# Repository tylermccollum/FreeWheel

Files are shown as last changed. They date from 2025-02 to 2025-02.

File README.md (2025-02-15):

BLDC motors represent an opportunity for massive improvements in hobby 
robotics work, but is largely limited by the cost. You can get a 
serviceable motor for less than $5, but the driver to use it starts at 
$40. The goal for this project is to create an open-source 100W BLDC 
servo controller design with a BOM cost under $10 and an accompanying 
library for control to standardize open-source FOC work.

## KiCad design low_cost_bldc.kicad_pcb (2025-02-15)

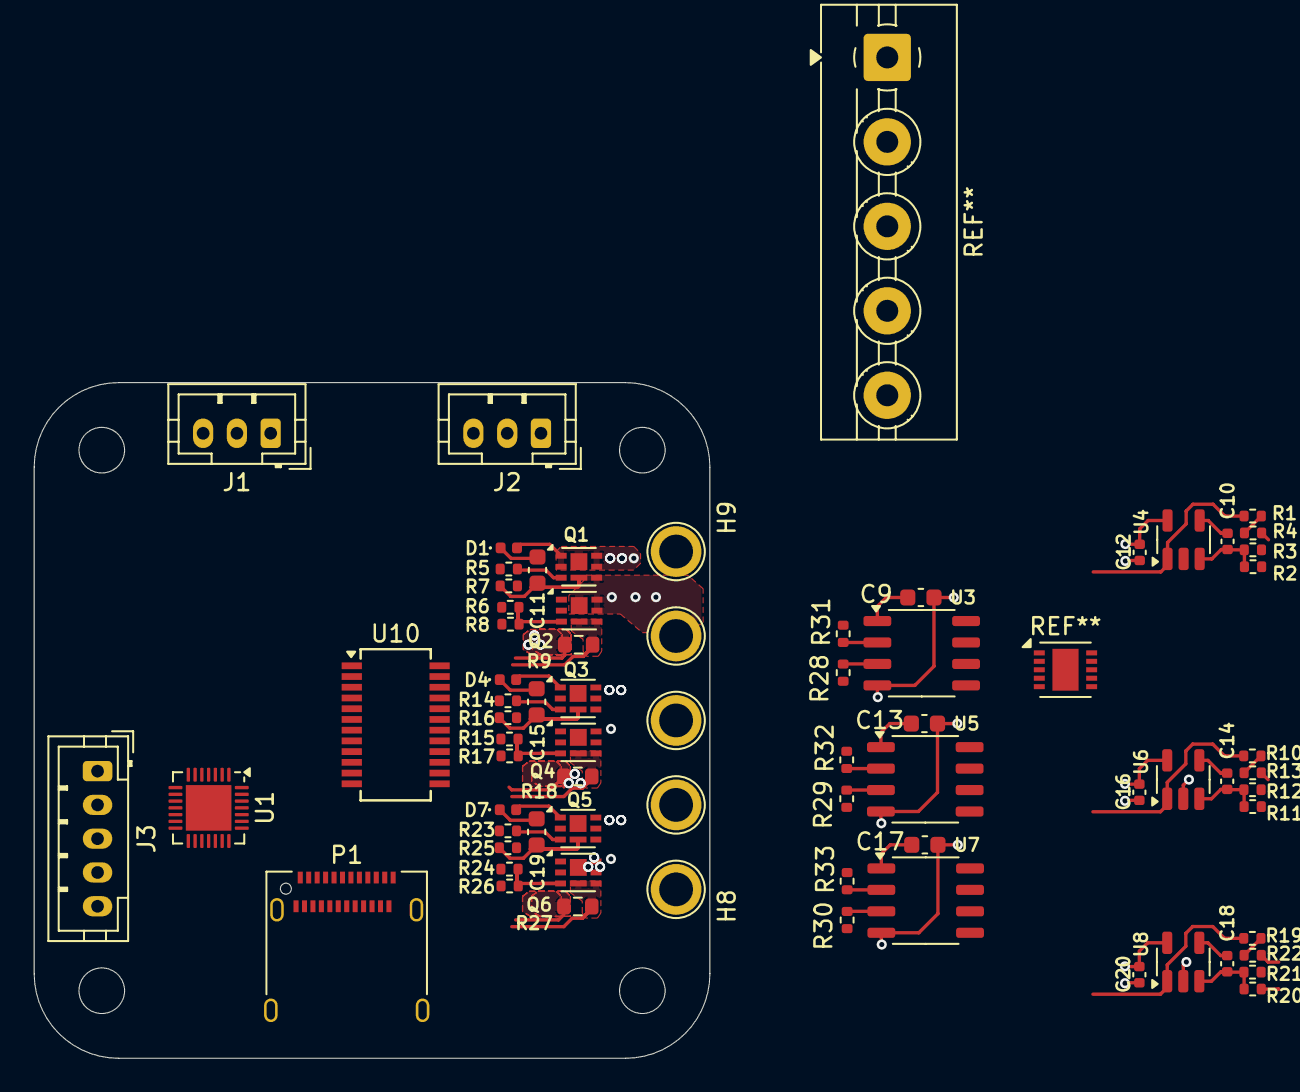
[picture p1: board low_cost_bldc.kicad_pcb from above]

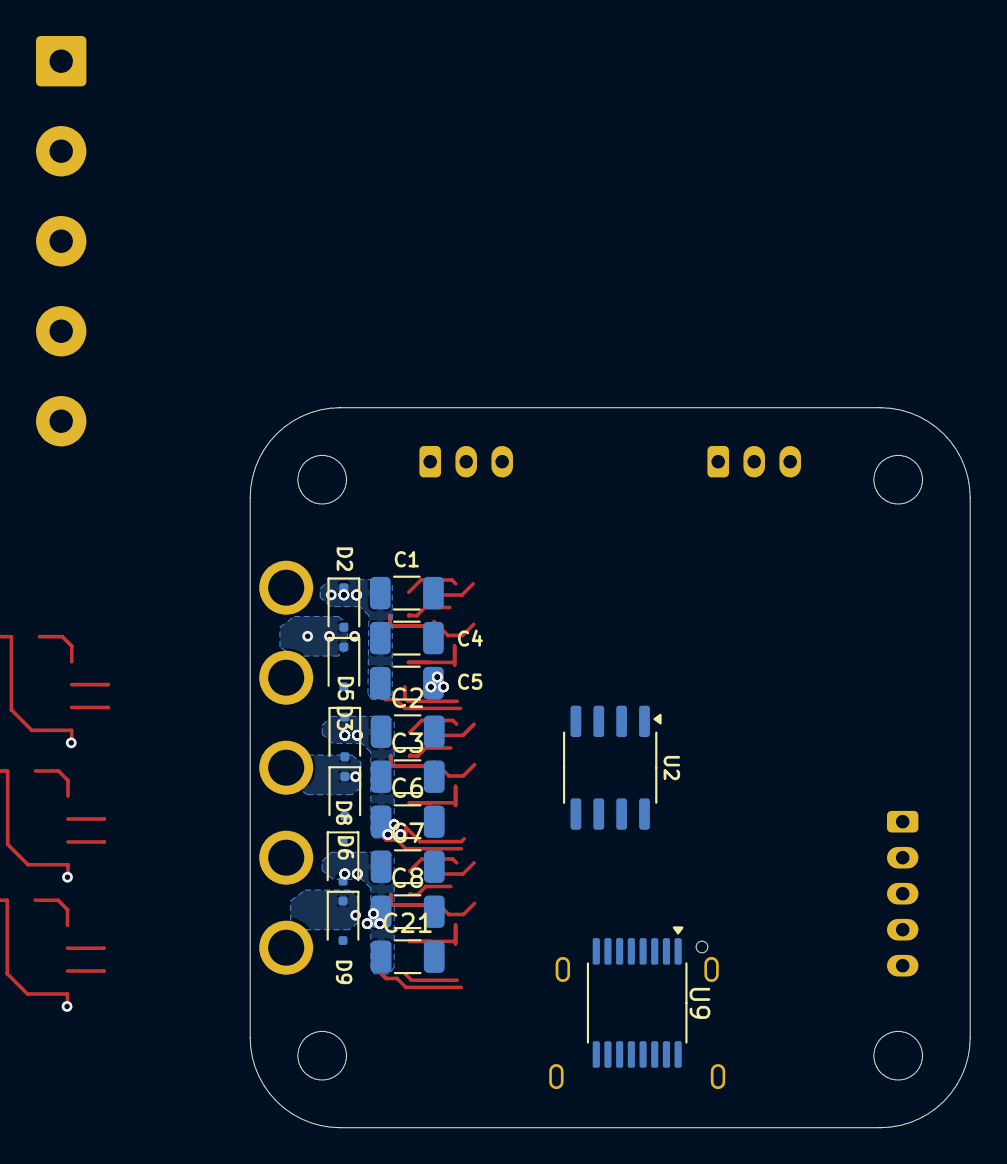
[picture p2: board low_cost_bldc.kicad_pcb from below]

Board: 4 copper layers, 40.0 x 40.0 mm, 92 parts (17 on the bottom side), 43 nets.

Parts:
C1, C2, C3, C4, C5, C6, C7, C8, C21: 10uF; C_1206_3216Metric
C9, C11, C13, C15, C17, C19: 1uF; C_0603_1608Metric
C10, C14, C18: C_Small; C_0402_1005Metric
C12, C16, C20: 0.1uF; C_0402_1005Metric
D1, D4, D7: D_Schottky_Filled; D_0402_1005Metric
D2, D3, D5, D6, D8, D9: D_Schottky_Filled; D_SOD-323F
H1, H2, H3, H4: MountingHole; MountingHole_2.7mm_M2.5
H5, H6, H7, H8, H9: MountingHole_Pad; TestPoint_Plated_Hole_D2.0mm
J1, J2: Conn_01x03; JST_PH_B3B-PH-K_1x03_P2.00mm_Vertical
J3: Conn_01x05; JST_PH_B5B-PH-K_1x05_P2.00mm_Vertical
P1: USB_C_Plug_USB2.0; USB_C_Receptacle_Amphenol_12401610E4-2A
Q1, Q2, Q3, Q4, Q5, Q6: HSCB3014; DFN-6-1EP_2x2mm_P0.65mm_2xEP
R1, R2, R10, R11, R19, R20: 47k; R_0402_1005Metric
R3, R4, R12, R13, R21, R22, R28, R29, R30, R31, R32, R33: 10k; R_0402_1005Metric
R5, R6, R14, R15, R23, R24: 10; R_0402_1005Metric
R7, R8, R16, R17, R25, R26: 1k; R_0402_1005Metric
R9, R18, R27: 10m; R_0603_1608Metric
U1: CH32V203GxUx; QFN-28-1EP_4x4mm_P0.4mm_EP2.7x2.7mm
U2: MT6701CT; SO-8_3.9x4.9mm_P1.27mm
U3, U5, U7: U2115C; SOP-8_3.9x4.9mm_P1.27mm
U4, U6, U8: COS8051; SOT-23-5
U9: IP2721; TSSOP-16_4.4x5mm_P0.65mm
U10: UC6310; SSOP-24_3.9x8.7mm_P0.635mm

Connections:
+3V3: C12.1, C16.1, C20.1, R28.2, R29.2, R30.2, U4.5 (VS+), U6.5 (VS+), U8.5 (VS+)
+12V: C9.1, C13.1, C17.1, U3.1 (VCC), U5.1 (VCC), U7.1 (VCC)
/Half-Bridge U/I_SENSE: R1.1, U4.1
/Half-Bridge U/PWM_HI: R31.2, U3.2 (HIN)
/Half-Bridge U/~PWM_LO: R28.1, U3.3 (~LIN)
/Half-Bridge V/I_SENSE: R10.1, U6.1
/Half-Bridge V/PWM_HI: R32.2, U5.2 (HIN)
/Half-Bridge V/~PWM_LO: R29.1, U5.3 (~LIN)
/Half-Bridge W/I_SENSE: R19.1, U8.1
/Half-Bridge W/PWM_HI: R33.2, U7.2 (HIN)
/Half-Bridge W/~PWM_LO: R30.1, U7.3 (~LIN)
/PHASE_U: C11.2, D2.2 (A), D3.1 (K), H5.1, Q1.4 (S), Q1.8 (S), Q2.1 (D), Q2.2 (D), Q2.5 (D), Q2.6 (D), Q2.7 (D), R7.2, U3.6 (VS)
/PHASE_V: C15.2, D5.2 (A), D6.1 (K), H6.1, Q3.4 (S), Q3.8 (S), Q4.1 (D), Q4.2 (D), Q4.5 (D), Q4.6 (D), Q4.7 (D), R16.2, U5.6 (VS)
/PHASE_W: C19.2, D8.2 (A), D9.1 (K), H7.1, Q5.4 (S), Q5.8 (S), Q6.1 (D), Q6.2 (D), Q6.5 (D), Q6.6 (D), Q6.7 (D), R25.2, U7.6 (VS)
GND: C1.2, C2.2, C3.2, C4.2, C5.2, C6.2, C7.2, C8.2, C9.2, C12.2, C13.2, C16.2, C17.2, C20.2, C21.2, D3.2 (A), D6.2 (A), D9.2 (A), H8.1, R2.1, R4.2, R8.2, R9.2, R11.1, R13.2, R17.2, R18.2, R20.1, R22.2, R26.2, R27.2, R31.1, R32.1, R33.1, U3.4 (COM), U4.2 (VS-), U5.4 (COM), U6.2 (VS-), U7.4 (COM), U8.2 (VS-)
unnamed: C11.1, D1.1 (K), U3.8 (VB)
unnamed: C15.1, D4.1 (K), U5.8 (VB)
unnamed: C19.1, D7.1 (K), U7.8 (VB)
unnamed: P1.A1 (GND), P1.A12 (GND), P1.B1 (GND), P1.B12 (GND)
unnamed: P1.A4 (VBUS), P1.A9 (VBUS), P1.B4 (VBUS), P1.B9 (VBUS)
unnamed: Q1.3 (G), R5.2, R7.1
unnamed: Q2.3 (G), R6.2, R8.1
unnamed: Q2.4 (S), Q2.8 (S), R3.2, R9.1
unnamed: Q3.3 (G), R14.2, R16.1
unnamed: Q4.3 (G), R15.2, R17.1
unnamed: Q4.4 (S), Q4.8 (S), R12.2, R18.1
unnamed: Q5.3 (G), R23.2, R25.1
unnamed: Q6.3 (G), R24.2, R26.1
unnamed: Q6.4 (S), Q6.8 (S), R21.2, R27.1
unnamed: U1.16 (VSS), U1.29 (VSS)
unnamed: R5.1, U3.7 (HO)
unnamed: R6.1, U3.5 (LO)
unnamed: C10.1, R2.2, R3.1, U4.3 (+)
unnamed: C10.2, R1.2, R4.1, U4.4 (-)
unnamed: R14.1, U5.7 (HO)
unnamed: R15.1, U5.5 (LO)
unnamed: C14.1, R11.2, R12.1, U6.3 (+)
unnamed: C14.2, R10.2, R13.1, U6.4 (-)
unnamed: R23.1, U7.7 (HO)
unnamed: R24.1, U7.5 (LO)
unnamed: C18.1, R20.2, R21.1, U8.3 (+)
unnamed: C18.2, R19.2, R22.1, U8.4 (-)
VBUS: C1.1, C2.1, C3.1, C4.1, C5.1, C6.1, C7.1, C8.1, C21.1, D1.2 (A), D2.1 (K), D4.2 (A), D5.1 (K), D7.2 (A), D8.1 (K), H9.1, Q1.1 (D), Q1.2 (D), Q1.5 (D), Q1.6 (D), Q1.7 (D), Q3.1 (D), Q3.2 (D), Q3.5 (D), Q3.6 (D), Q3.7 (D), Q5.1 (D), Q5.2 (D), Q5.5 (D), Q5.6 (D), Q5.7 (D)

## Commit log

2025-01-21 Top-only inverter layout
    [low_cost_bldc-inverter.kicad_sch, low_cost_bldc-mcu.kicad_sch, low_cost_bldc-power.kicad_sch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]
2025-01-21 Initial mounting holes, power lugs. Sitting at @ qty 10 BOM estimate. Still need 12V, 3.3V power; comms connectors
    [low_cost_bldc.kicad_pcb, low_cost_bldc.kicad_sch]
2025-01-21 Stop tracking backups
    [Phase.kicad_sch]
2025-01-24 Readme, rough connector placement, inverter refinement, increase MCU pin count to have a chance of succeeding.
    [low_cost_bldc-mcu.kicad_sch, low_cost_bldc.kicad_pcb, low_cost_bldc.kicad_sch]
2025-02-15 Move connectors
    [low_cost_bldc.kicad_sch]
2025-02-15 Re-save pcbdoc
    [low_cost_bldc.kicad_pcb]
